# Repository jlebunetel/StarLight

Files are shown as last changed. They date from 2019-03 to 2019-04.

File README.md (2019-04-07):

# StarLight
_StarLight_ est un jeu de ping-pong à une dimension où chaque joueur se renvoie la balle à tour de rôle. Un ruban de led multicolores permet de matérialiser les raquettes et la balle qui se déplace d’un côté à l’autre, tandis que les scores s’affichent sur un écran à matrice de led multicolore.

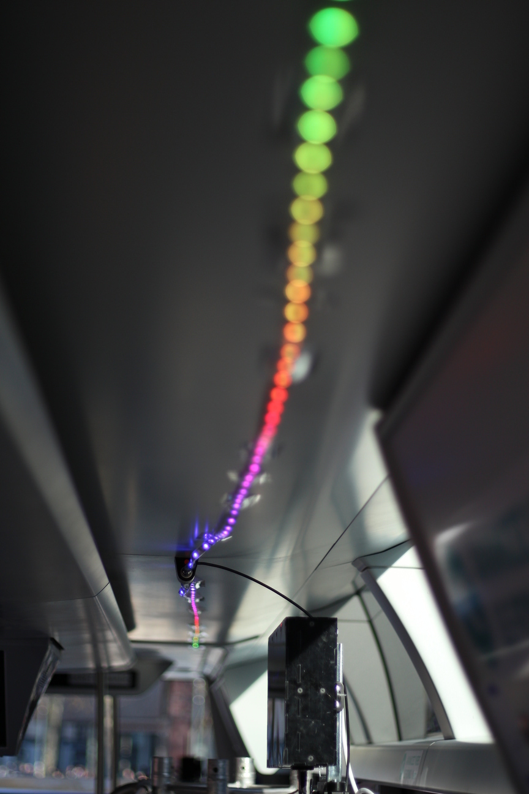
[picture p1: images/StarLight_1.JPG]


Créé lors du hackathon MétroMix 2017 à Rennes, ce jeu a été amélioré pour être intégré dans un bus lors de l’événement inOut 2019 à Rennes.

## Matériel nécessaire

__Attention : cette documentation est en cours de rédaction ...__

 * des plaques de PMMA noir opaques et translucides 3mm
 * une plaque de contreplaqué peuplier 3mm
 * du PLA pour les pièces imprimées en 3D
 * un Arduino Mega
 * une bande de LEDs RGB adressables de type *NeoPixel*
 * deux matrices de led 32 x 32
 * un Teensy 3.5
 * deux boutons d'arcade
 * une alimentation 220 V / 24 V (100W)
 * un condensateur électrolytique 1000 μF / 10 V
 * deux résistances 470 Ω
 * deux résistances 10 kΩ
 * deux condensateurs céramique 102 (1 nF)
 * un peu de câble ...

## Montage

L'ensemble des plans et des modèles 3D sont disponibles dans le dossier [models](models).

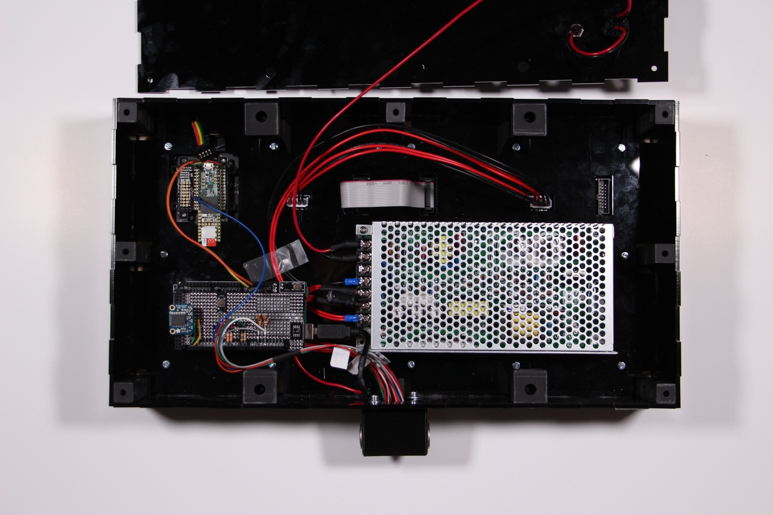
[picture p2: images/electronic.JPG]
Electronique


Les bandes de led sont alimentées en 5V et nécessitent la présence d'un condensateur de 1000 μF en parallèlele de l'alimentation.
On ajoute la résistance 470 Ω en série au signal.

LEDs

## Liens utiles

 * [Documentation du projet MétroMix 2017](http://www.wiki-rennes.fr/M%C3%A9troMix_2017/StarLight) ;

## Photos dans le bus lors d'inOut 2019
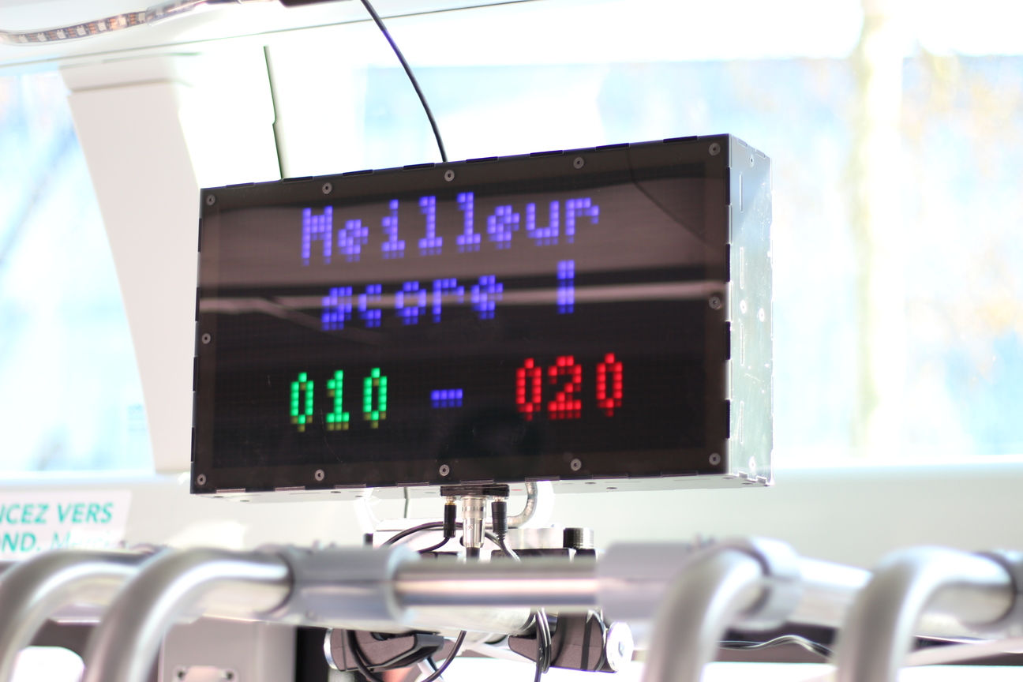
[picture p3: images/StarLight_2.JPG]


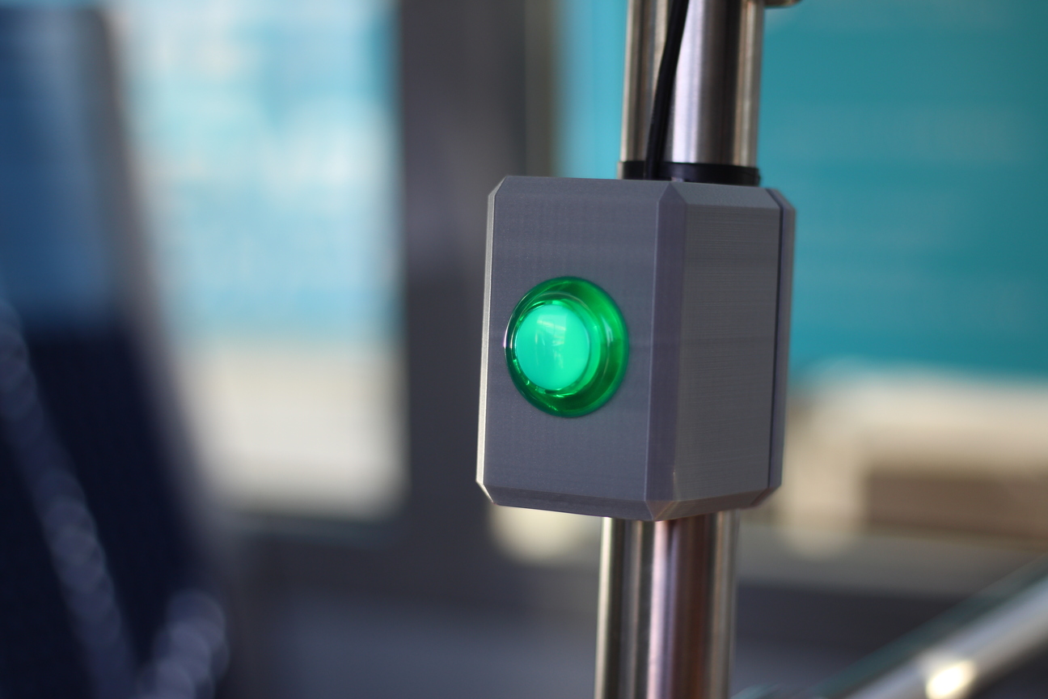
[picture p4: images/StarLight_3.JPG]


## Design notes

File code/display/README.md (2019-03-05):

# firmware for Teensy 3.5

## available commands

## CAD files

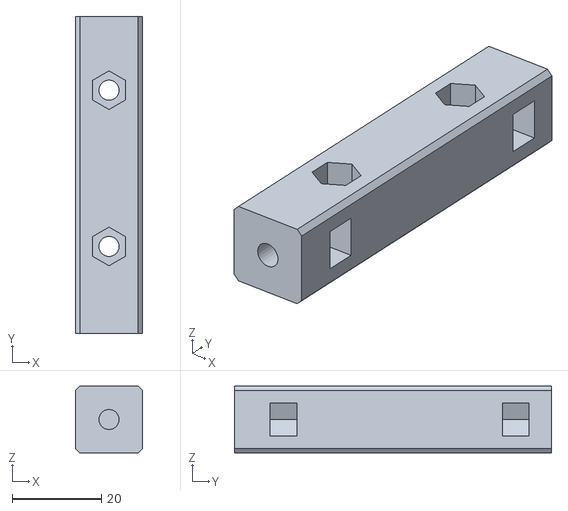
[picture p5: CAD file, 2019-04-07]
models/entretoises/milieu.stl
15.0 x 71.0 x 15.0

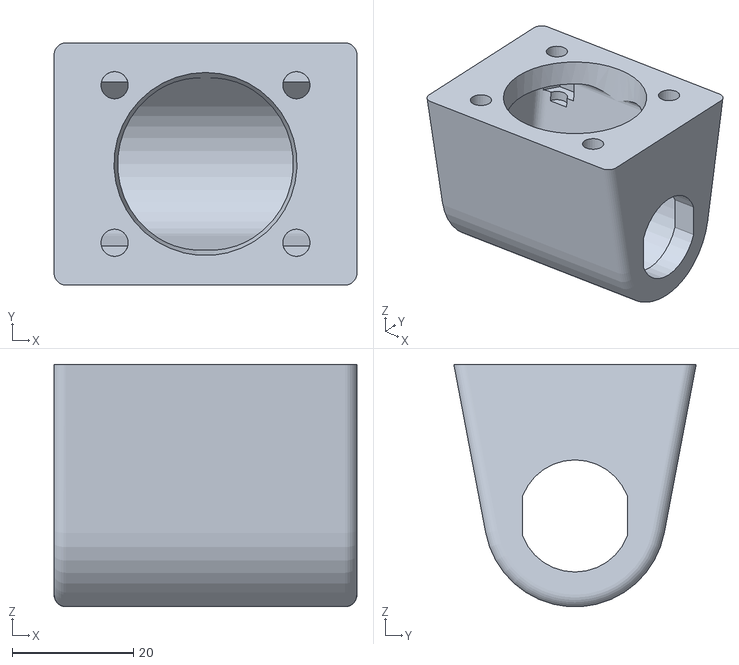
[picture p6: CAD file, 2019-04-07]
models/support_ruban.stl
50.0 x 40.0 x 40.0

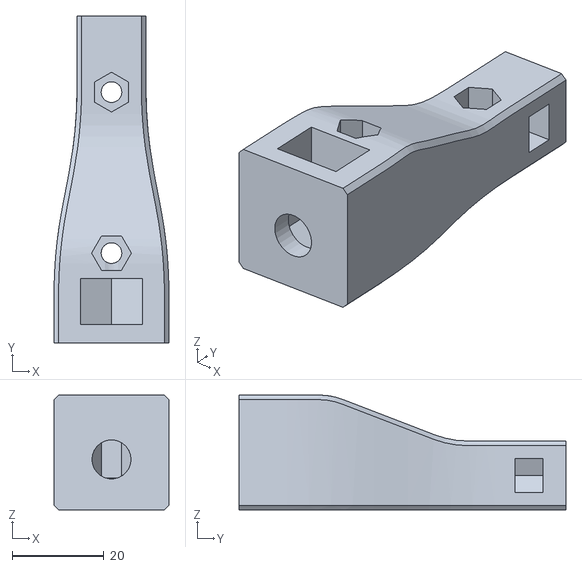
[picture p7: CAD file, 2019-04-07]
models/entretoises/support_M8.stl
25.0 x 71.0 x 25.0

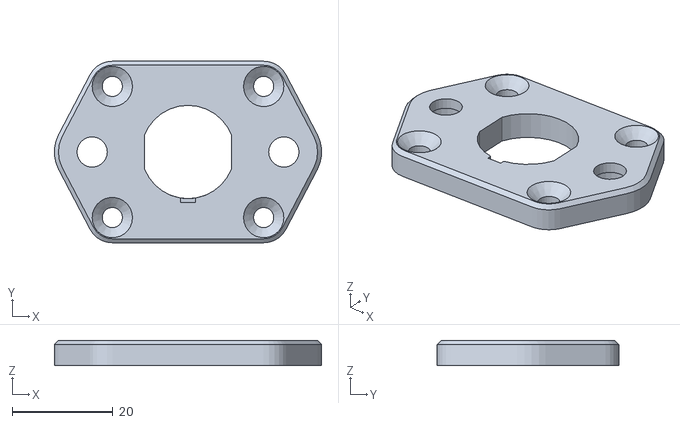
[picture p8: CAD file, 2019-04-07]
models/passage_connecteurs.stl
52.9 x 36.0 x 5.00

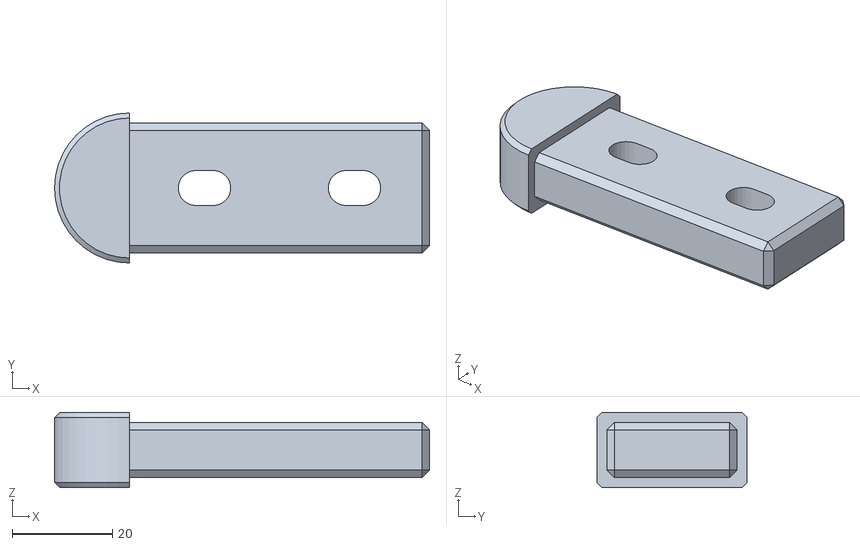
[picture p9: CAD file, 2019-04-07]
models/embout_support.stl
75.0 x 30.0 x 15.0

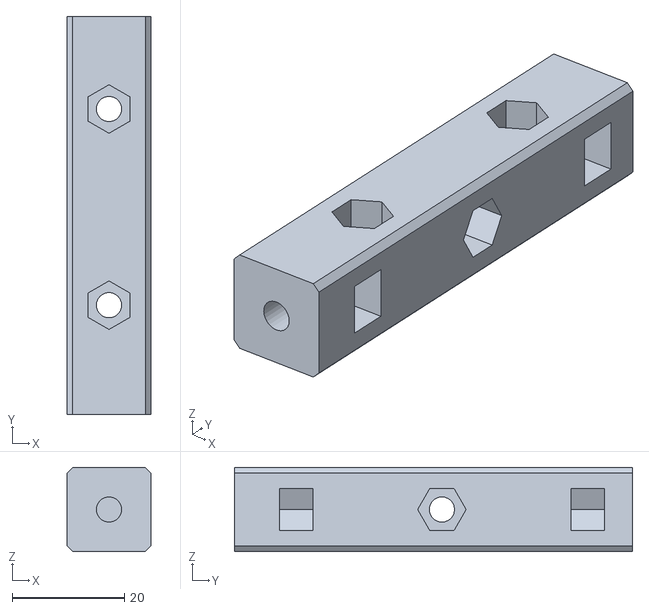
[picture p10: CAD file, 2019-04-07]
models/entretoises/angle.stl
15.0 x 71.0 x 15.0

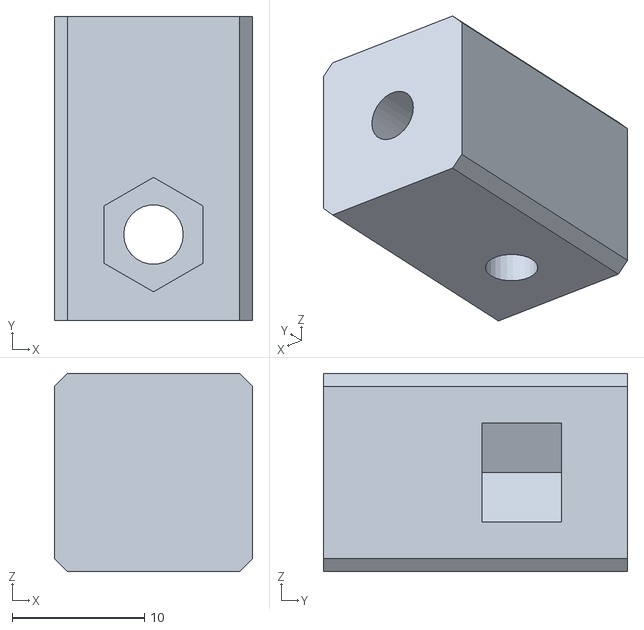
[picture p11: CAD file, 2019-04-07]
models/entretoises/milieu_court.stl
15.0 x 23.0 x 15.0

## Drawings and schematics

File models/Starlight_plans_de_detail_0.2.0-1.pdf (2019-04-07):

A

B

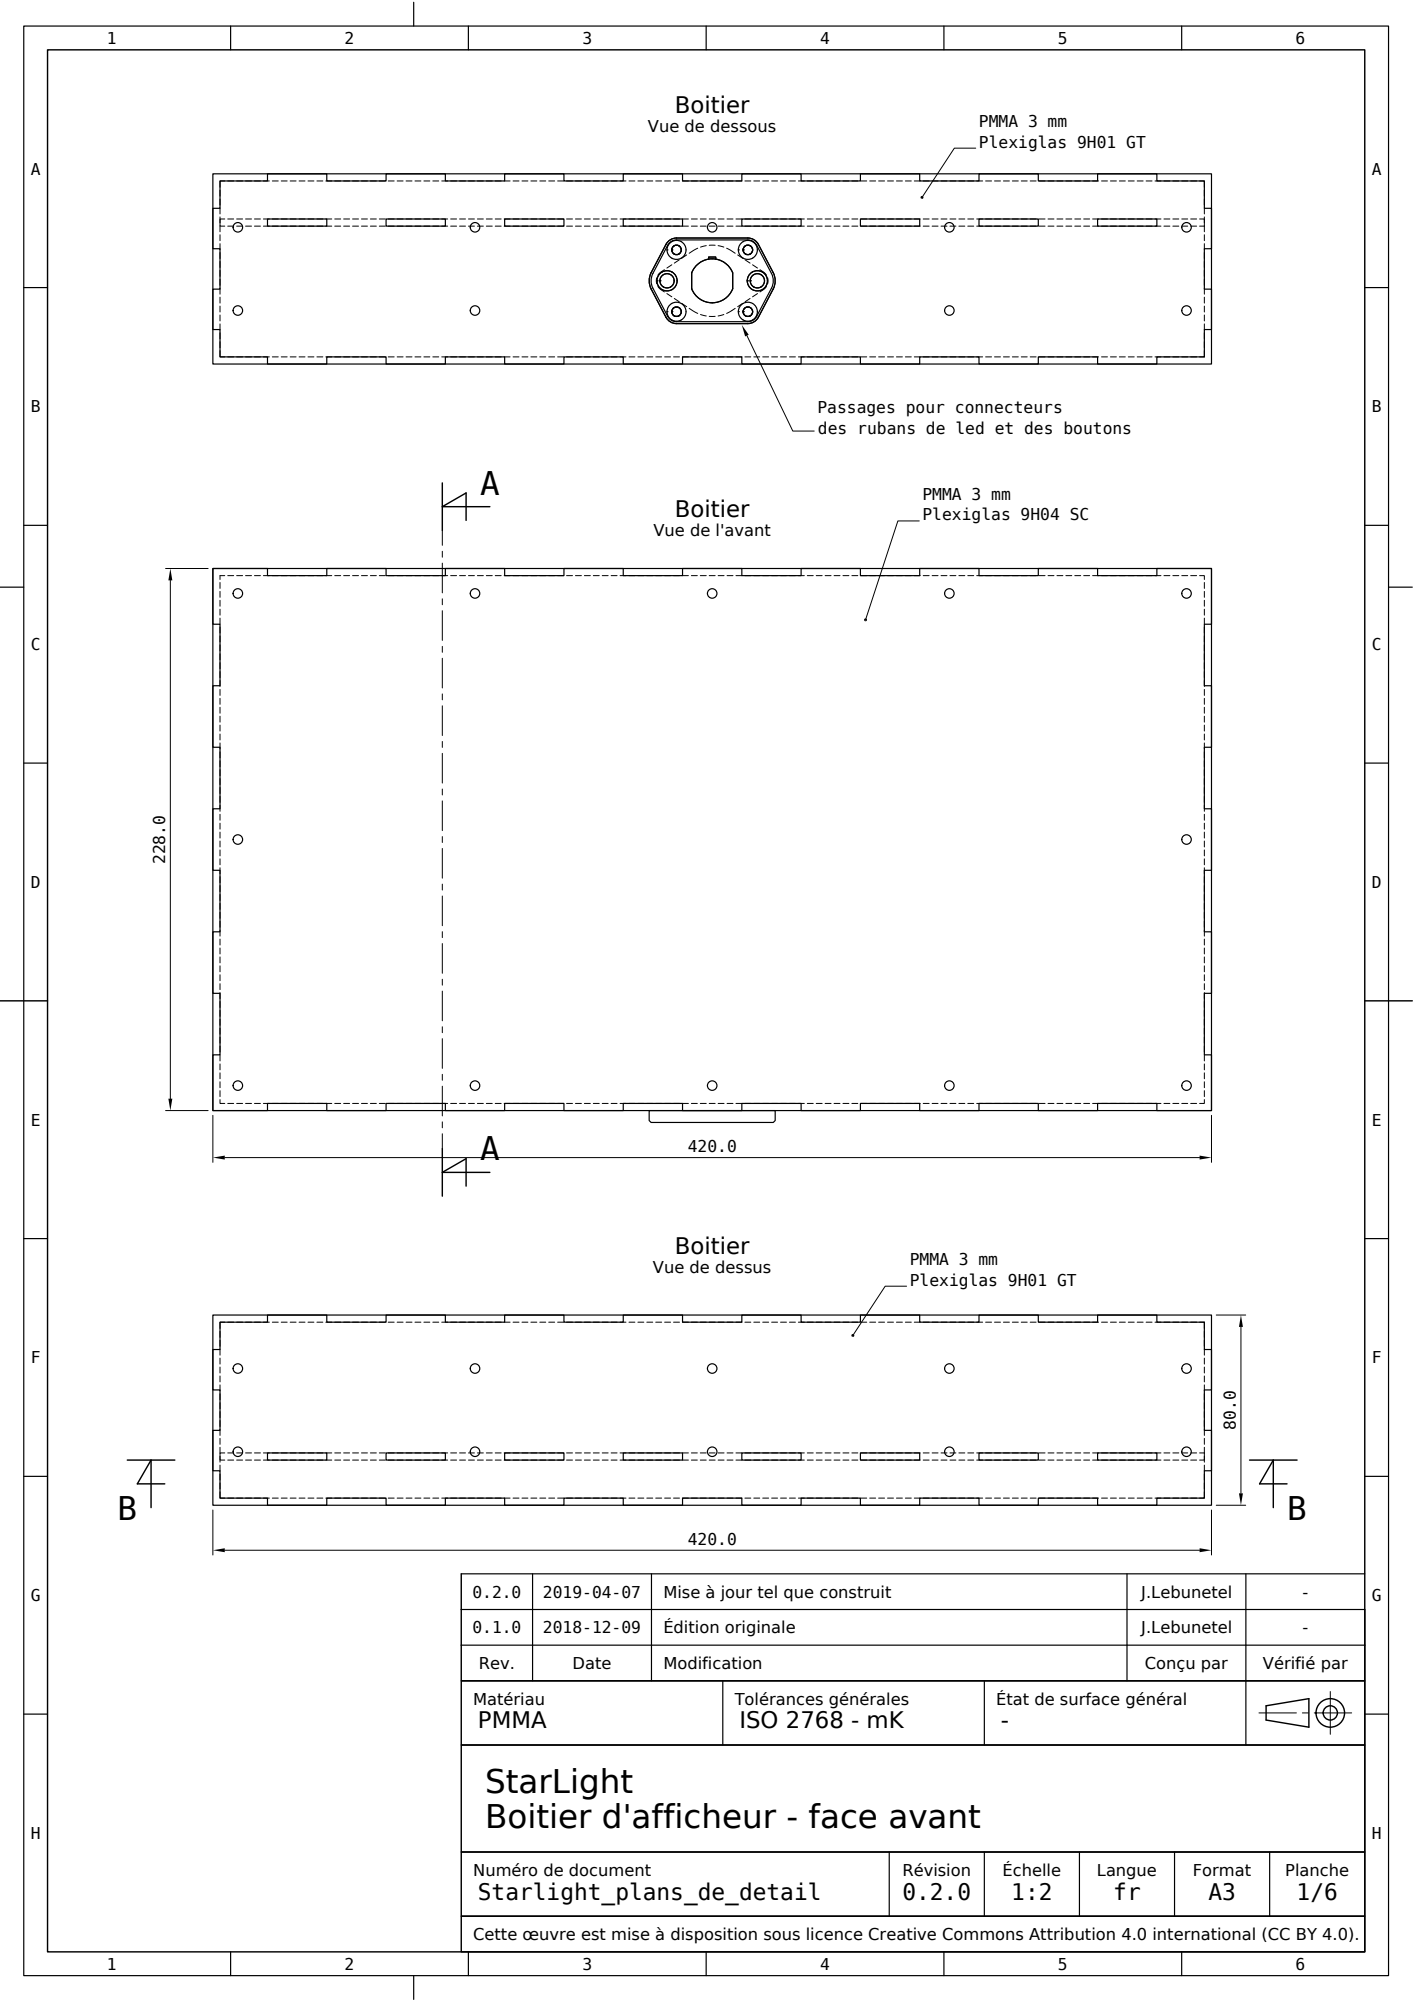
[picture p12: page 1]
Boitier; PMMA 3 mm; Plexiglas; Boitier d'afficheur -; face avant; StarLight; PMMA; ISO 2768 -; Rev.; Date; Modification; Édition originale; Lebunetel; Conçu par; Vérifié par; Matériau; Tolérances générales; État de surface général; Planche 1/6; Format A3; Langue fr; Échelle 1:2; Révision; Starlight_; plans_; detail; Cette uvre est mise à disposition sous licence Creative Commons Attribution 4.; 0 international (CC BY 4.; Passages; pour; connecteurs; des; rubans; led et des; boutons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

Vue de dessous

Vue de l'avant

Vue de dessus

Numéro de document

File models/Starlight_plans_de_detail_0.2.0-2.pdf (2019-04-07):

A

B

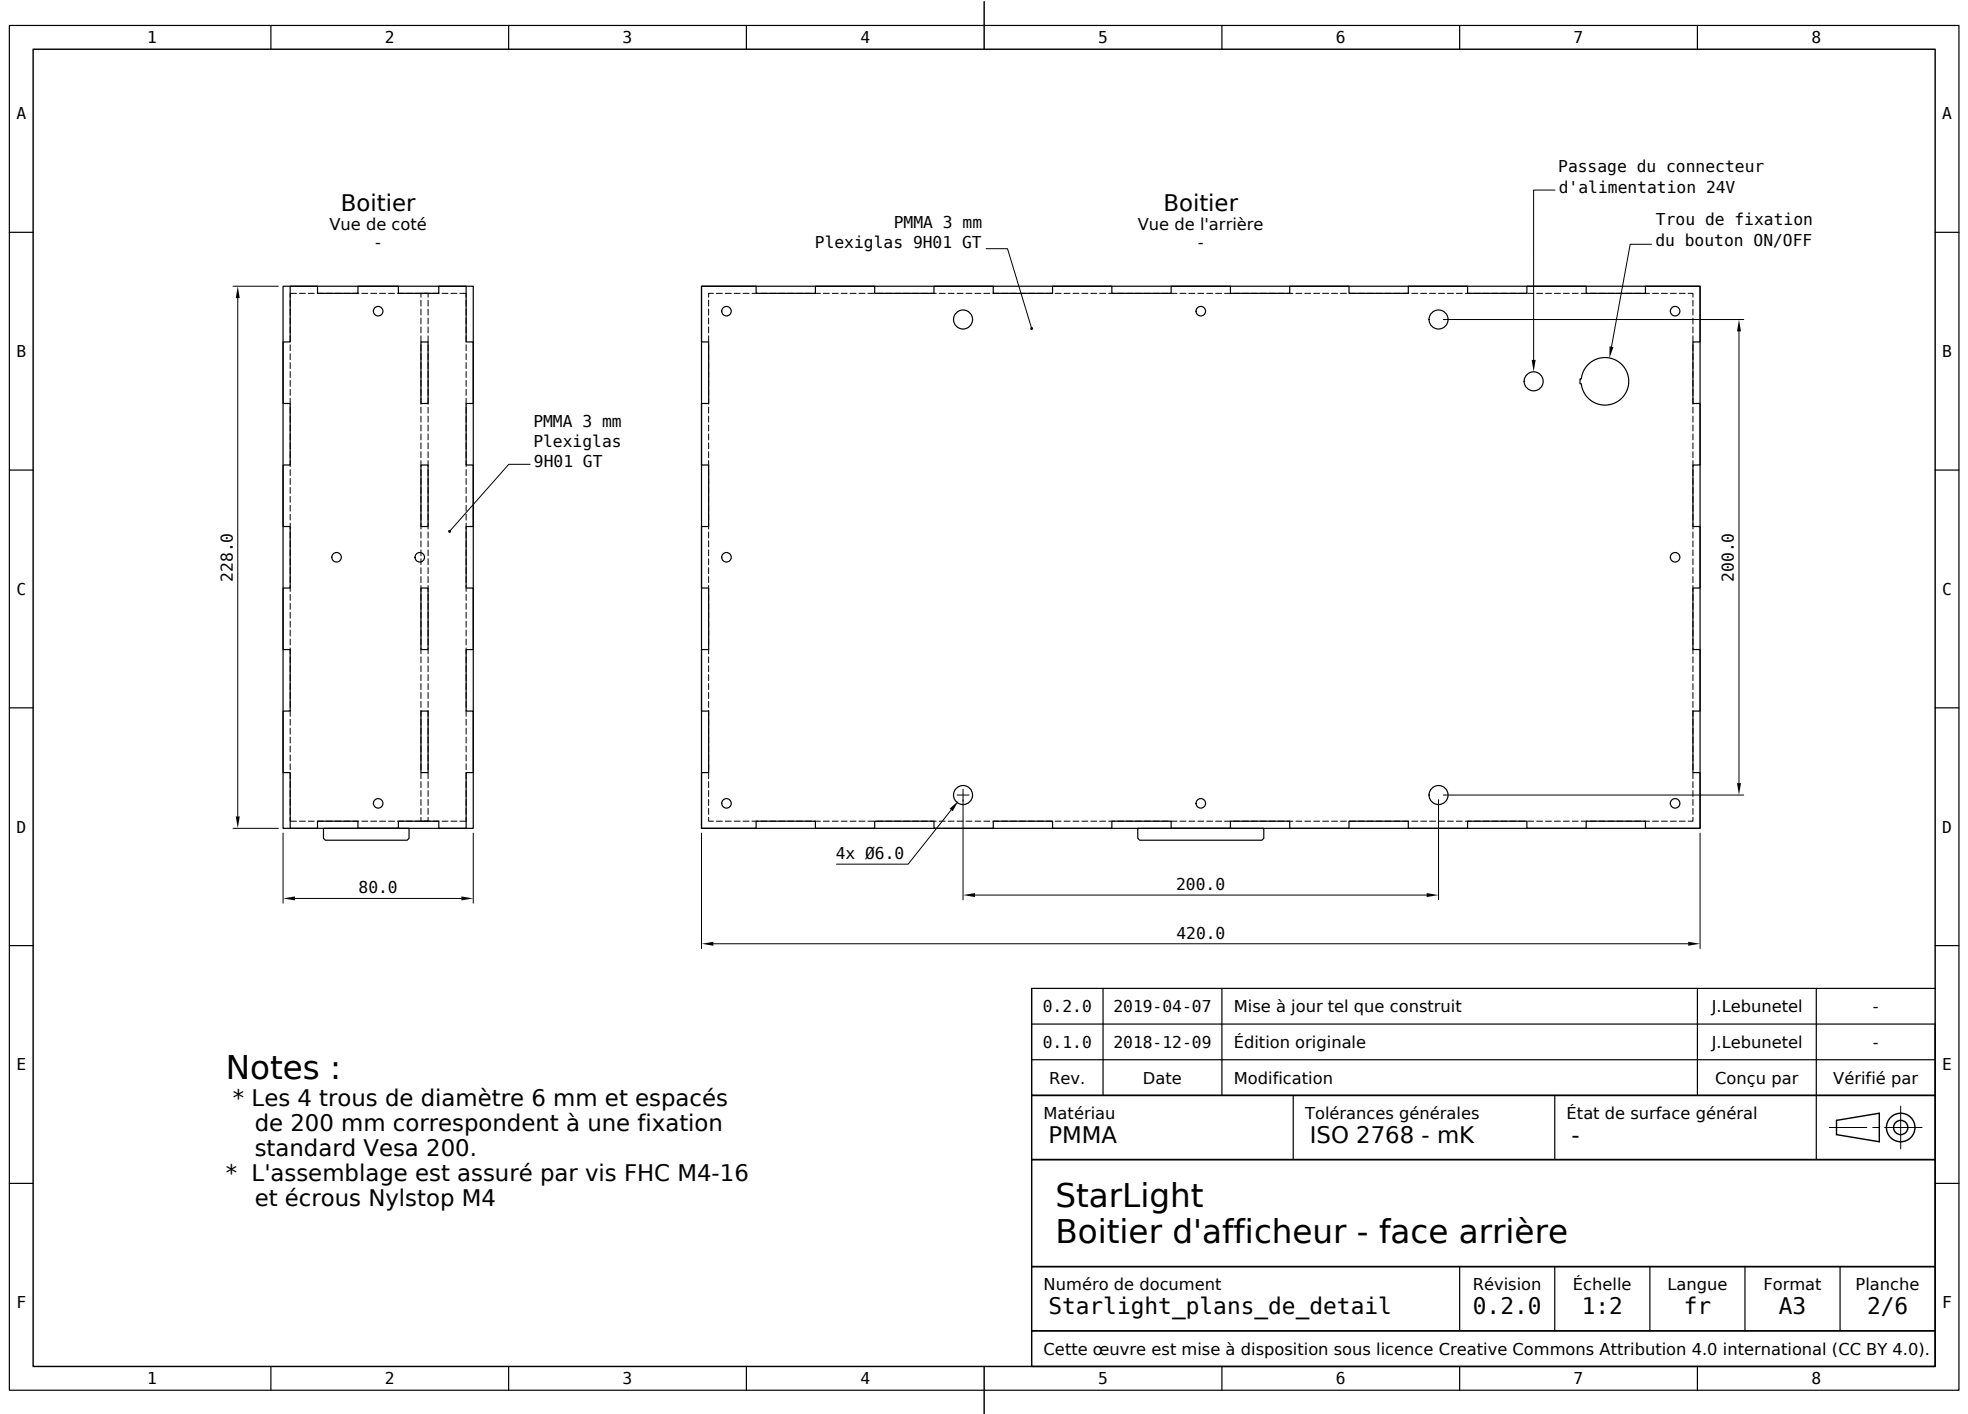
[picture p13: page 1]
Boitier; PMMA 3 mm; Plexiglas; Passage; connecteur; d'alimentation; Trou; fixation; bouton; ON/OFF; Boitier d'afficheur -; face arrière; StarLight; PMMA; ISO 2768 -; Rev.; Date; Modification; Édition originale; Lebunetel; Conçu par; Vérifié par; Matériau; Tolérances générales; État de surface général; Planche 2/6; Format A3; Langue fr; Échelle 1:2; Révision; Starlight_; plans_; detail; Cette uvre est mise à disposition sous licence Creative Commons Attribution 4.; 0 international (CC BY 4.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

Vue de coté

Vue de l'arrière

* Les 4 trous de diamètre 6 mm et espacés
de 200 mm correspondent à une fixation

standard Vesa 200.
et écrous Nylstop M4

Numéro de document

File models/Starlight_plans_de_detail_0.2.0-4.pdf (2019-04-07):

A

B

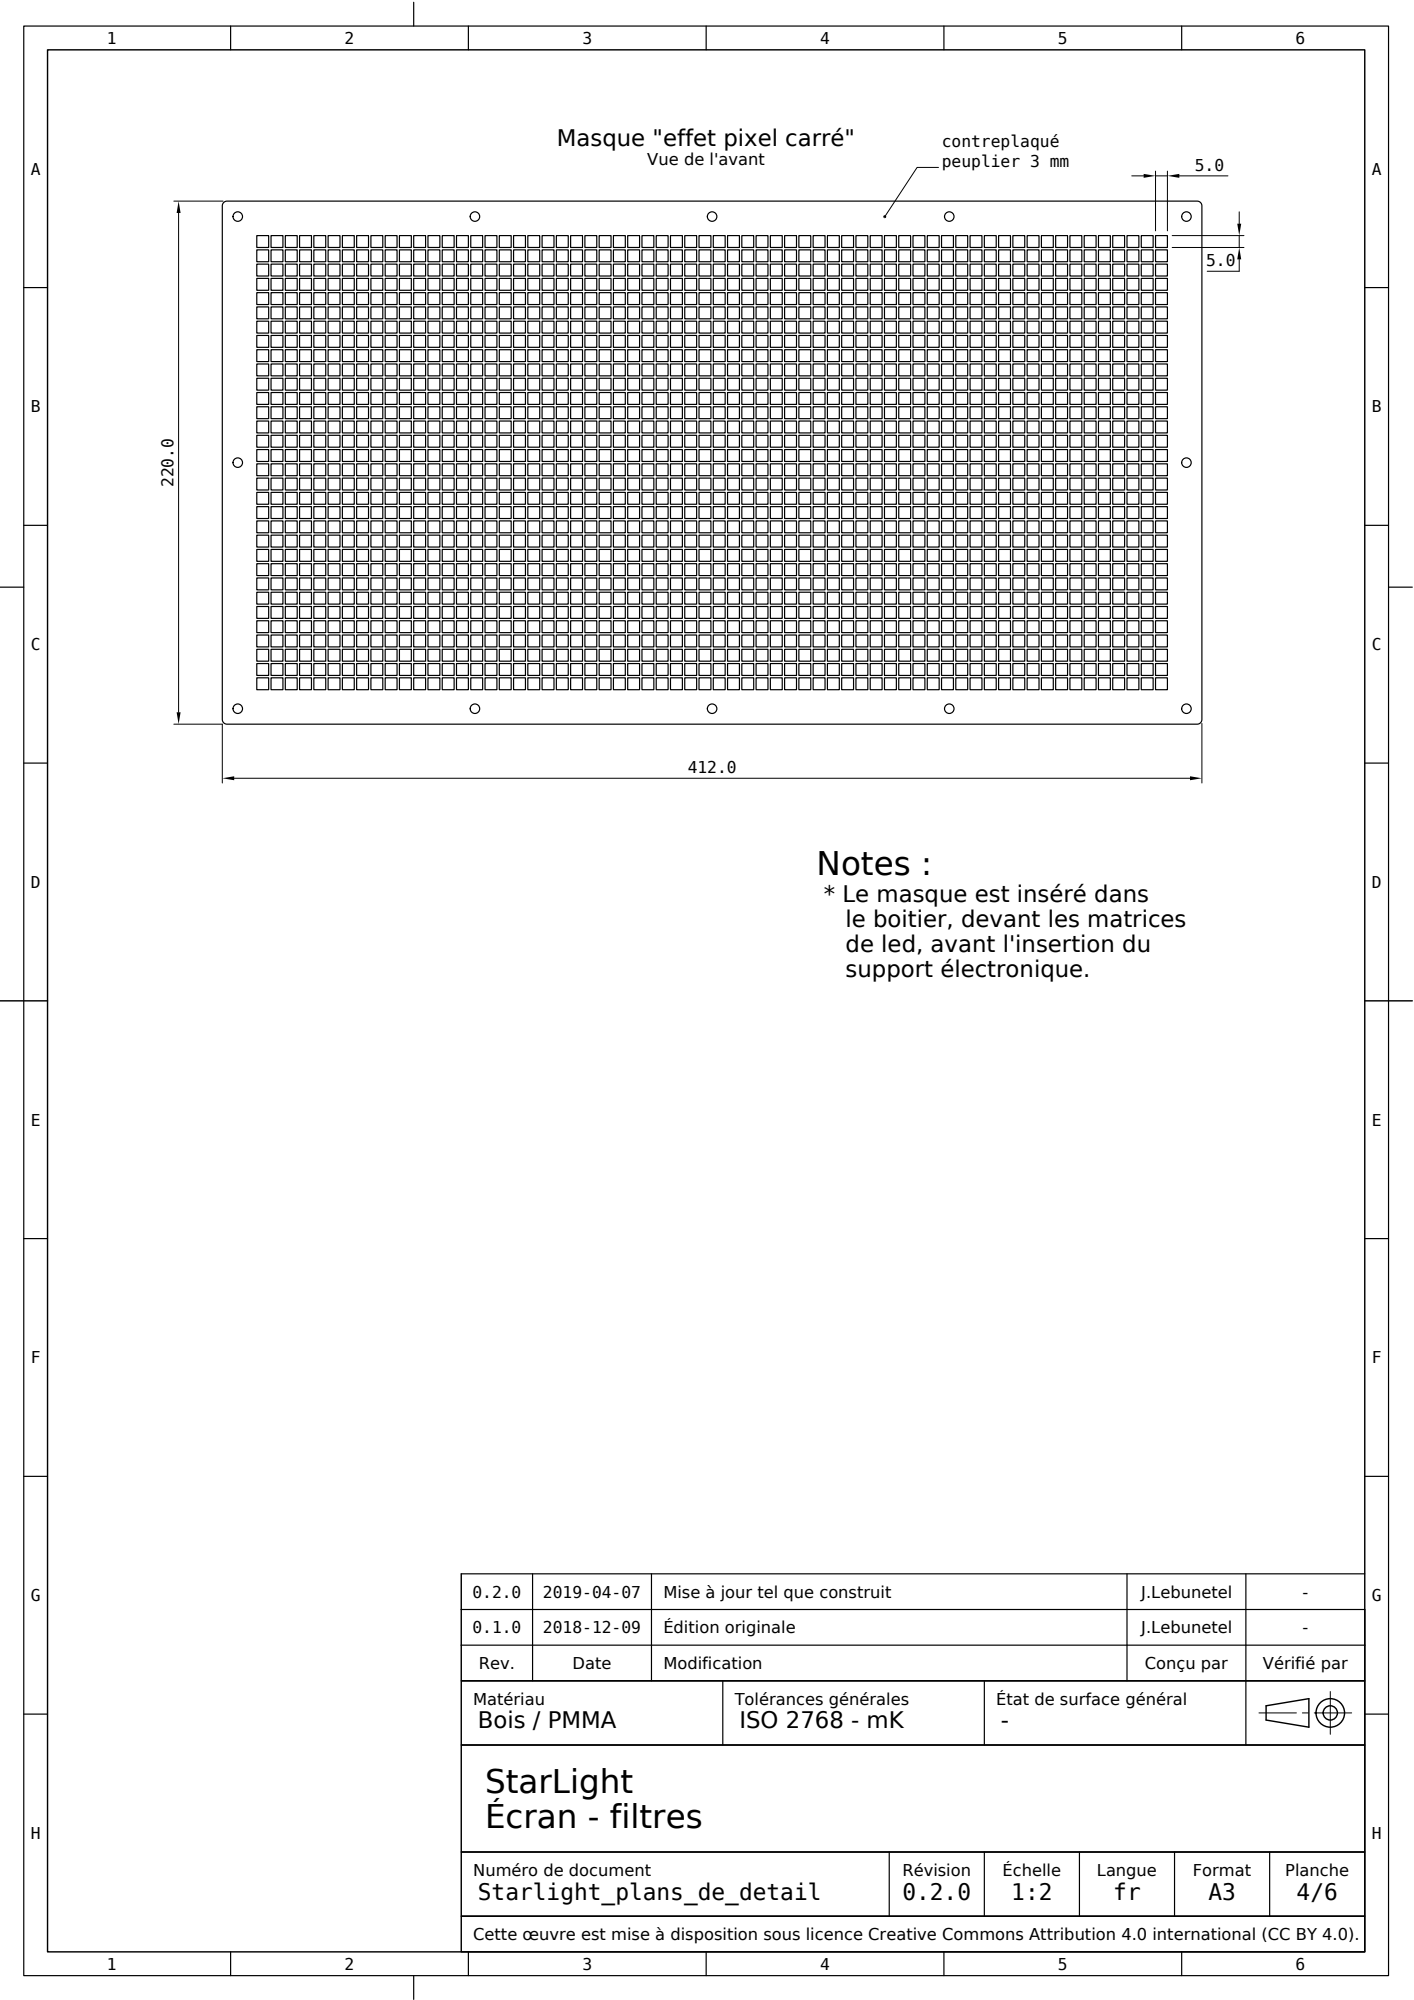
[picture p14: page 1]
Écran -; filtres; StarLight; Bois / PMMA; ISO 2768 -; Rev.; Date; Modification; Édition originale; Lebunetel; Conçu par; Vérifié par; Matériau; Tolérances générales; État de surface général; Planche 4/6; Format A3; Langue fr; Échelle 1:2; Révision; Starlight_; plans_; detail; Cette uvre est mise à disposition sous licence Creative Commons Attribution 4.; 0 international (CC BY 4.; contreplaqué; peuplier; Notes :; le boitier,; devant les matrices; de led,; avant l'insertion du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

Masque "effet pixel carré"

Vue de l'avant

* Le masque est inséré dans

Numéro de document

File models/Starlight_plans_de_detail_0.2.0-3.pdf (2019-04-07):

## Section A-A

A

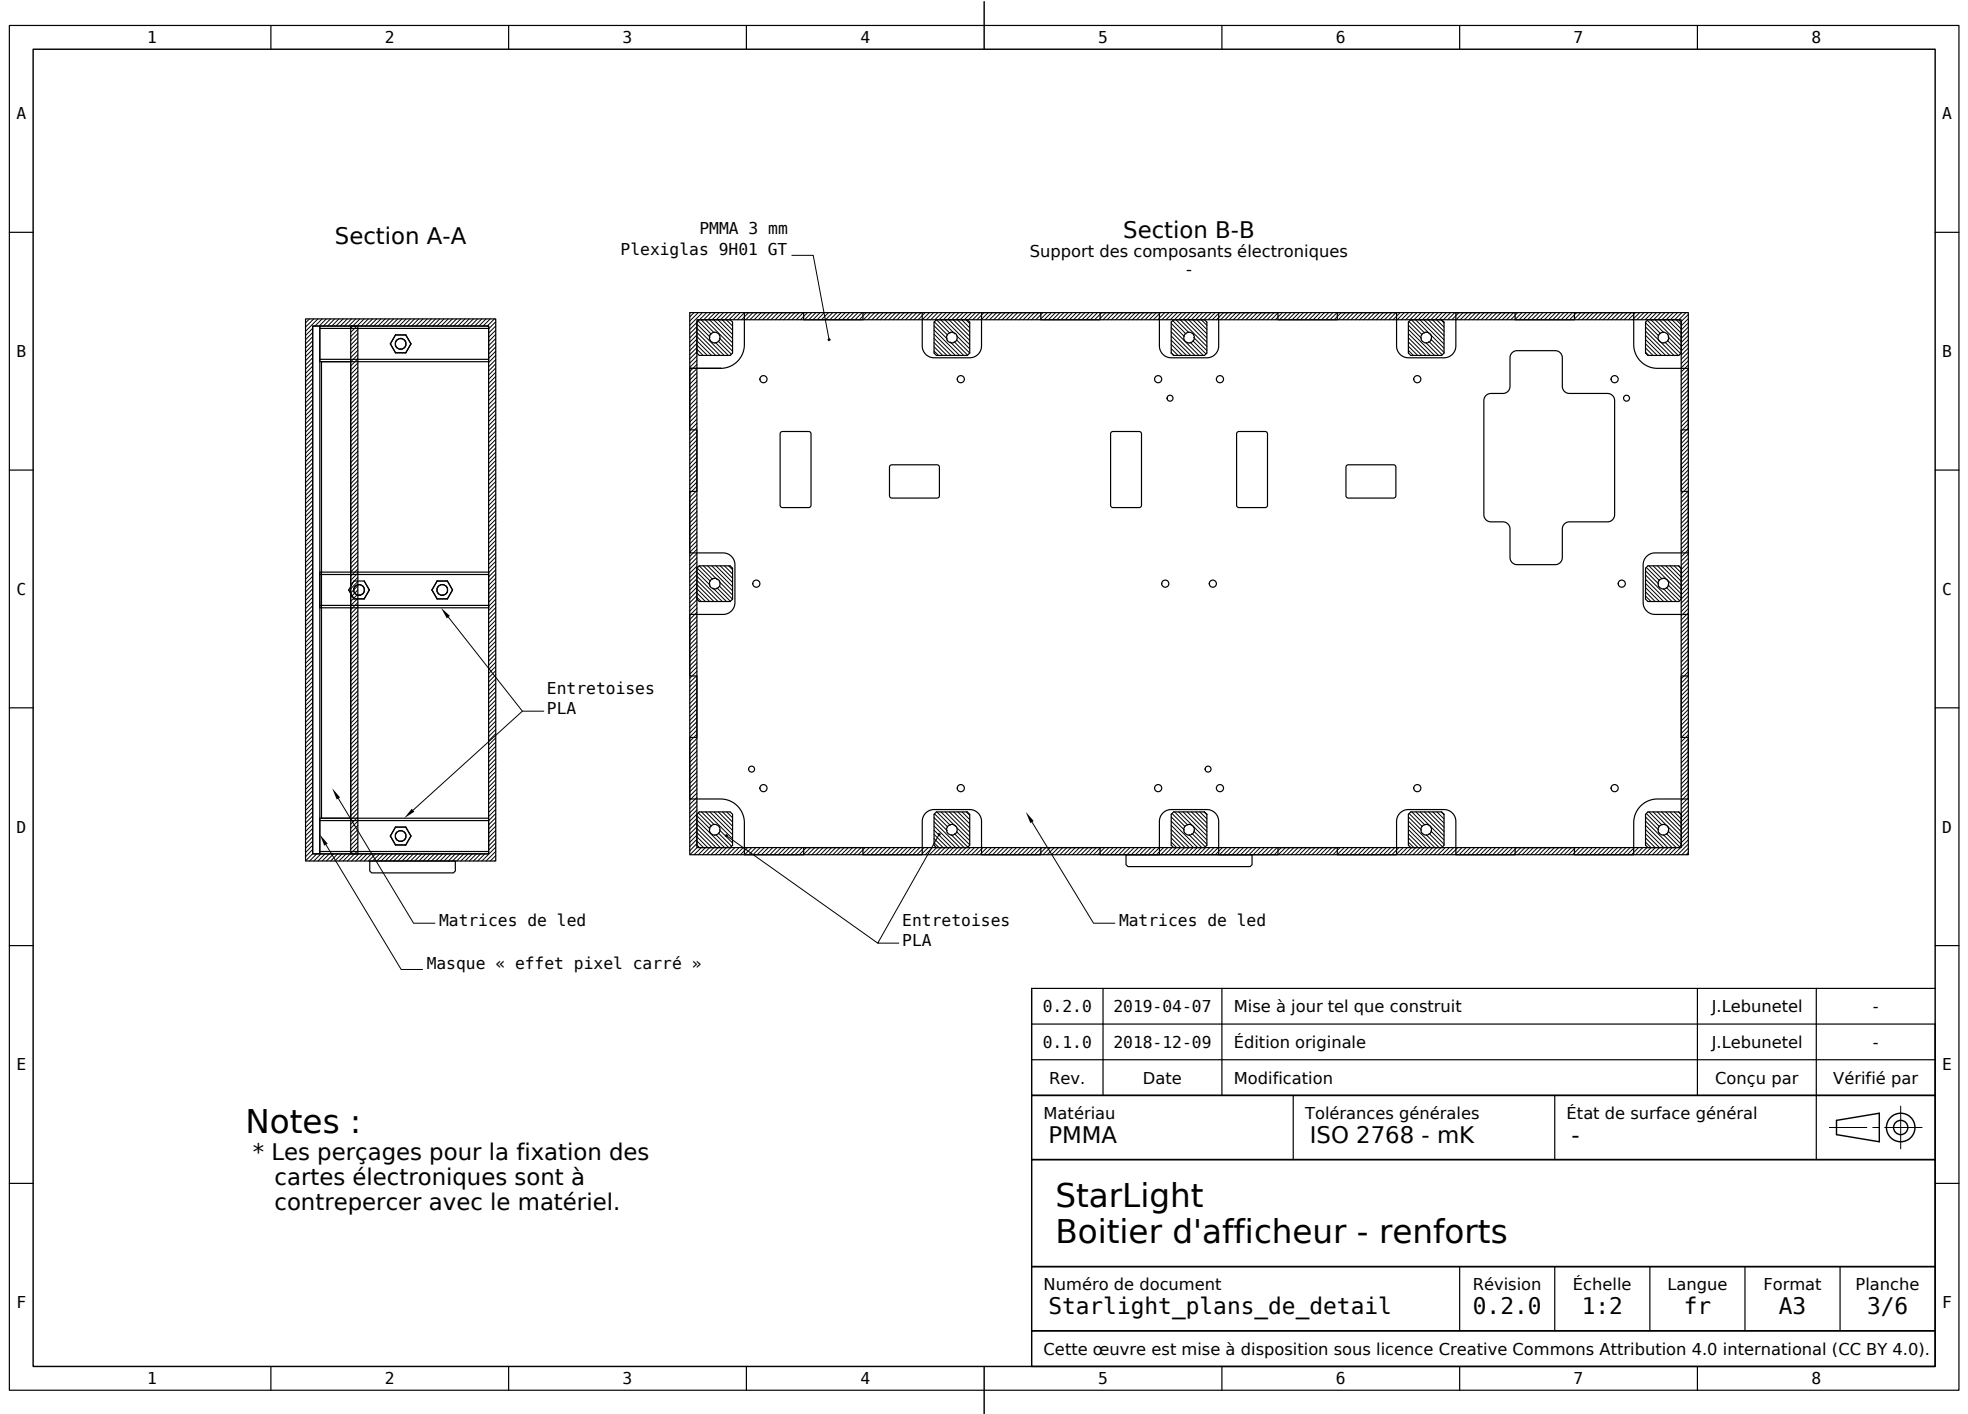
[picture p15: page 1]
Section B-; Boitier d'afficheur -; renforts; StarLight; PMMA; ISO 2768 -; Rev.; Date; Modification; Édition originale; Lebunetel; Conçu par; Vérifié par; Matériau; Tolérances générales; État de surface général; Planche 3/6; Format A3; Langue fr; Échelle 1:2; Révision; Starlight_; plans_; detail; Cette uvre est mise à disposition sous licence Creative Commons Attribution 4.; 0 international (CC BY 4.; Mise à jour tel que construit; PMMA 3 mm; Plexiglas; Masque; effet pixel carré »; Matrices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

Support des composants électroniques

* Les perçages pour la fixation des
cartes électroniques sont à
contrepercer avec le matériel.

Numéro de document

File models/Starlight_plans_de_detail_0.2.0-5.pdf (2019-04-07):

A

B

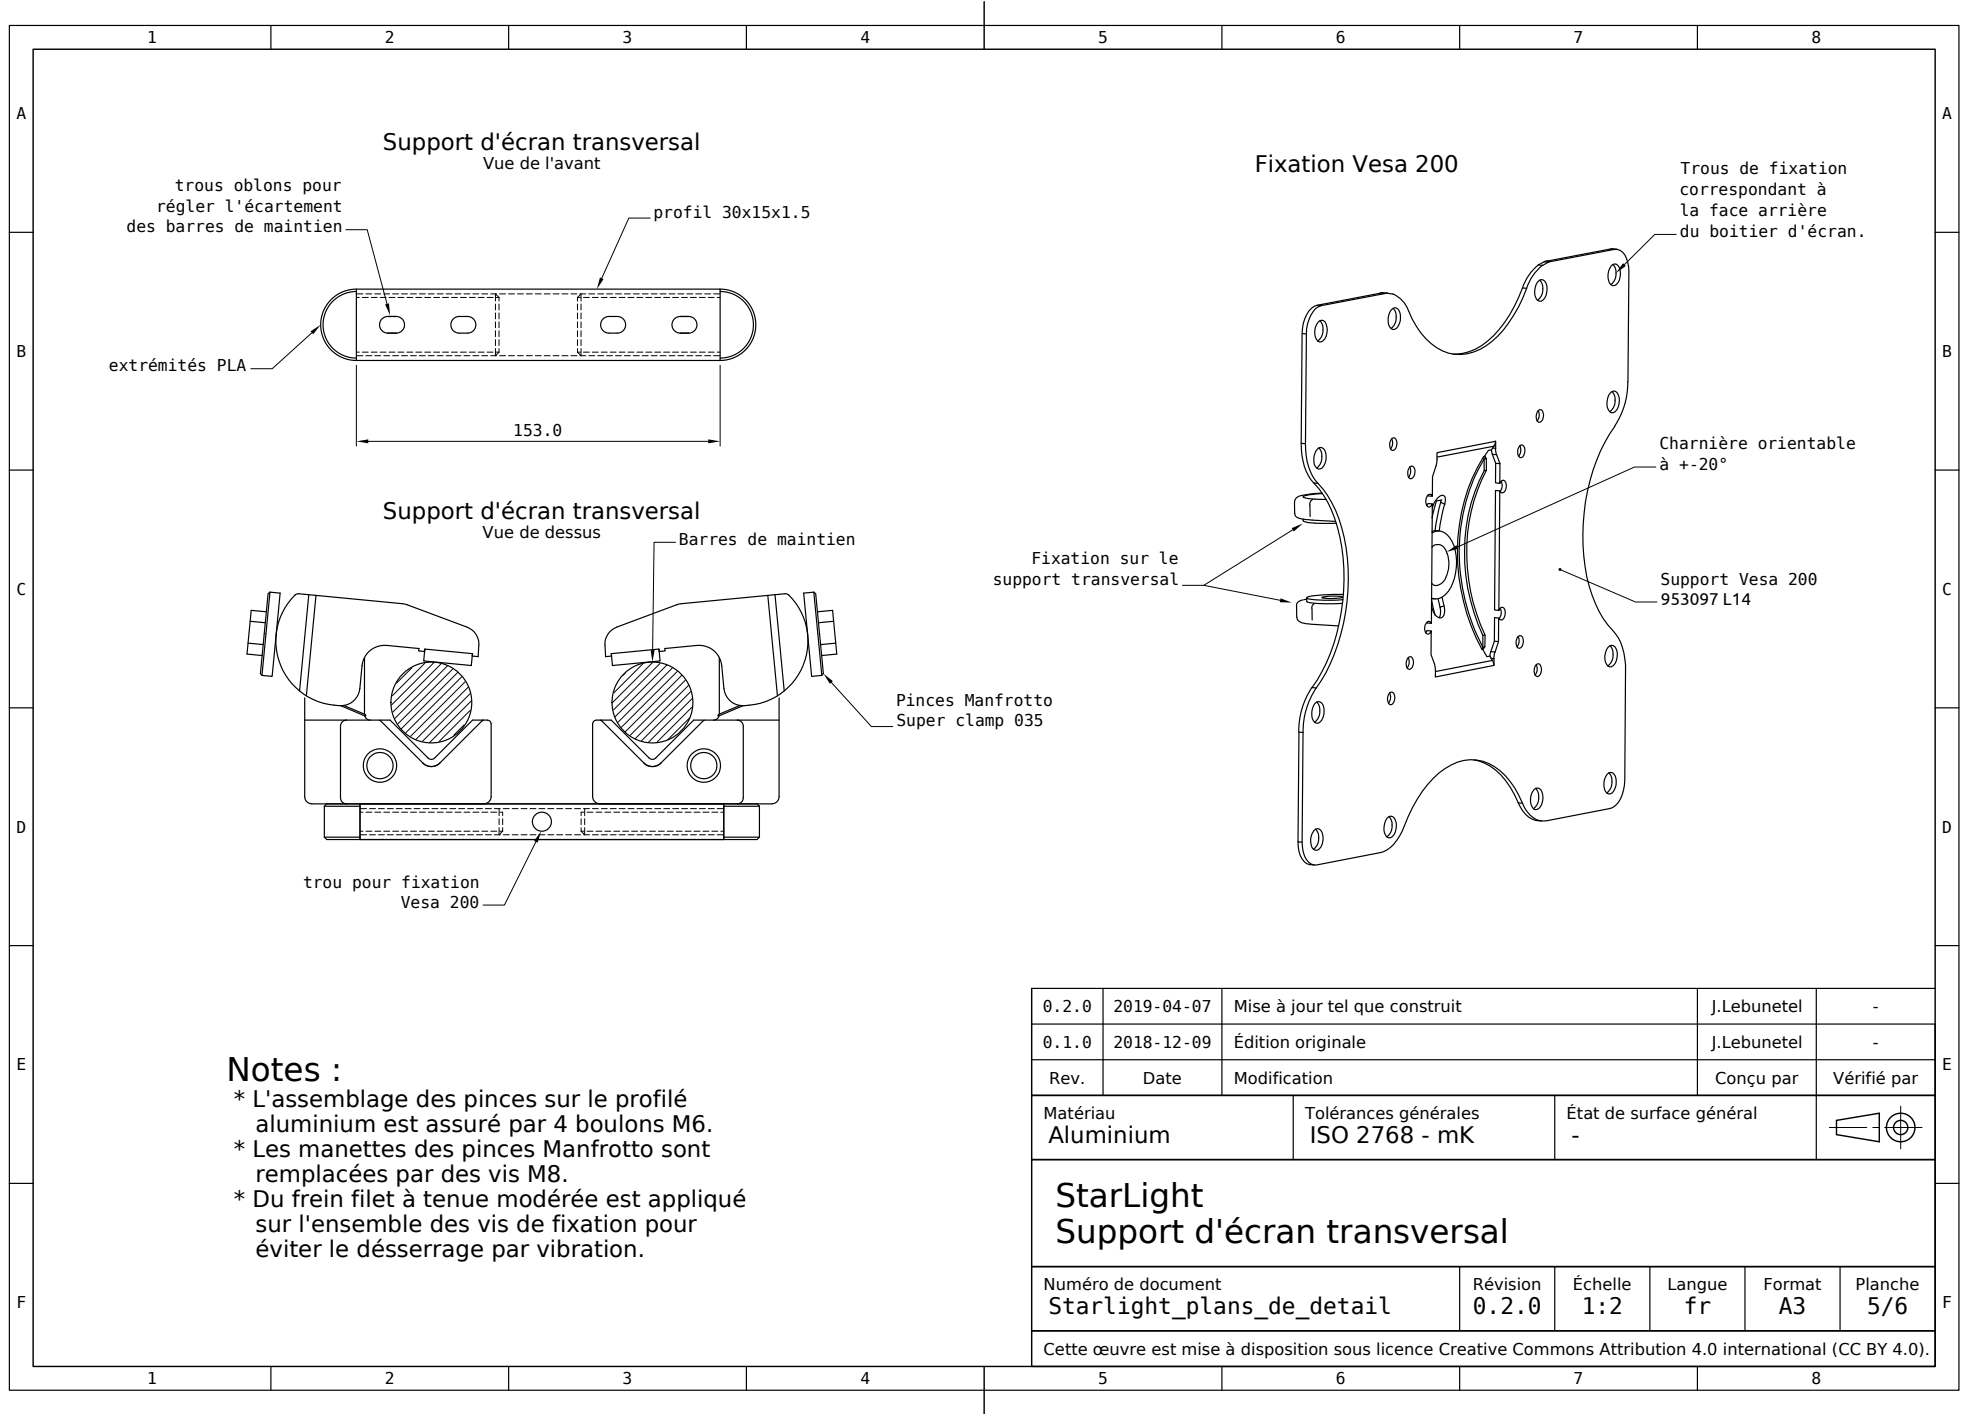
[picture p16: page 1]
Aluminium; ISO 2768 -; Rev.; Date; Modification; Édition originale; Lebunetel; Conçu par; Vérifié par; Matériau; Tolérances générales; État de surface général; Planche 5/6; Format A3; Langue fr; Échelle 1:2; Révision; Starlight_; plans_; detail; Cette uvre est mise à disposition sous licence Creative Commons Attribution 4.; 0 international (CC BY 4.; Notes :; trous; oblons; pour; régler; l'écartement; des; barres; maintien; extrémités; PLA; Mise à jour tel que construit; trou; fixation; Vesa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

Support d'écran transversal

Vue de l'avant

Vue de dessus

* L'assemblage des pinces sur le profilé
aluminium est assuré par 4 boulons M6.

* Les manettes des pinces Manfrotto sont
remplacées par des vis M8.
* Du frein filet à tenue modérée est appliqué

StarLight

sur l'ensemble des vis de fixation pour
éviter le désserrage par vibration.

Numéro de document

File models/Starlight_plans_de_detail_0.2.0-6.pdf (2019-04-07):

A

B

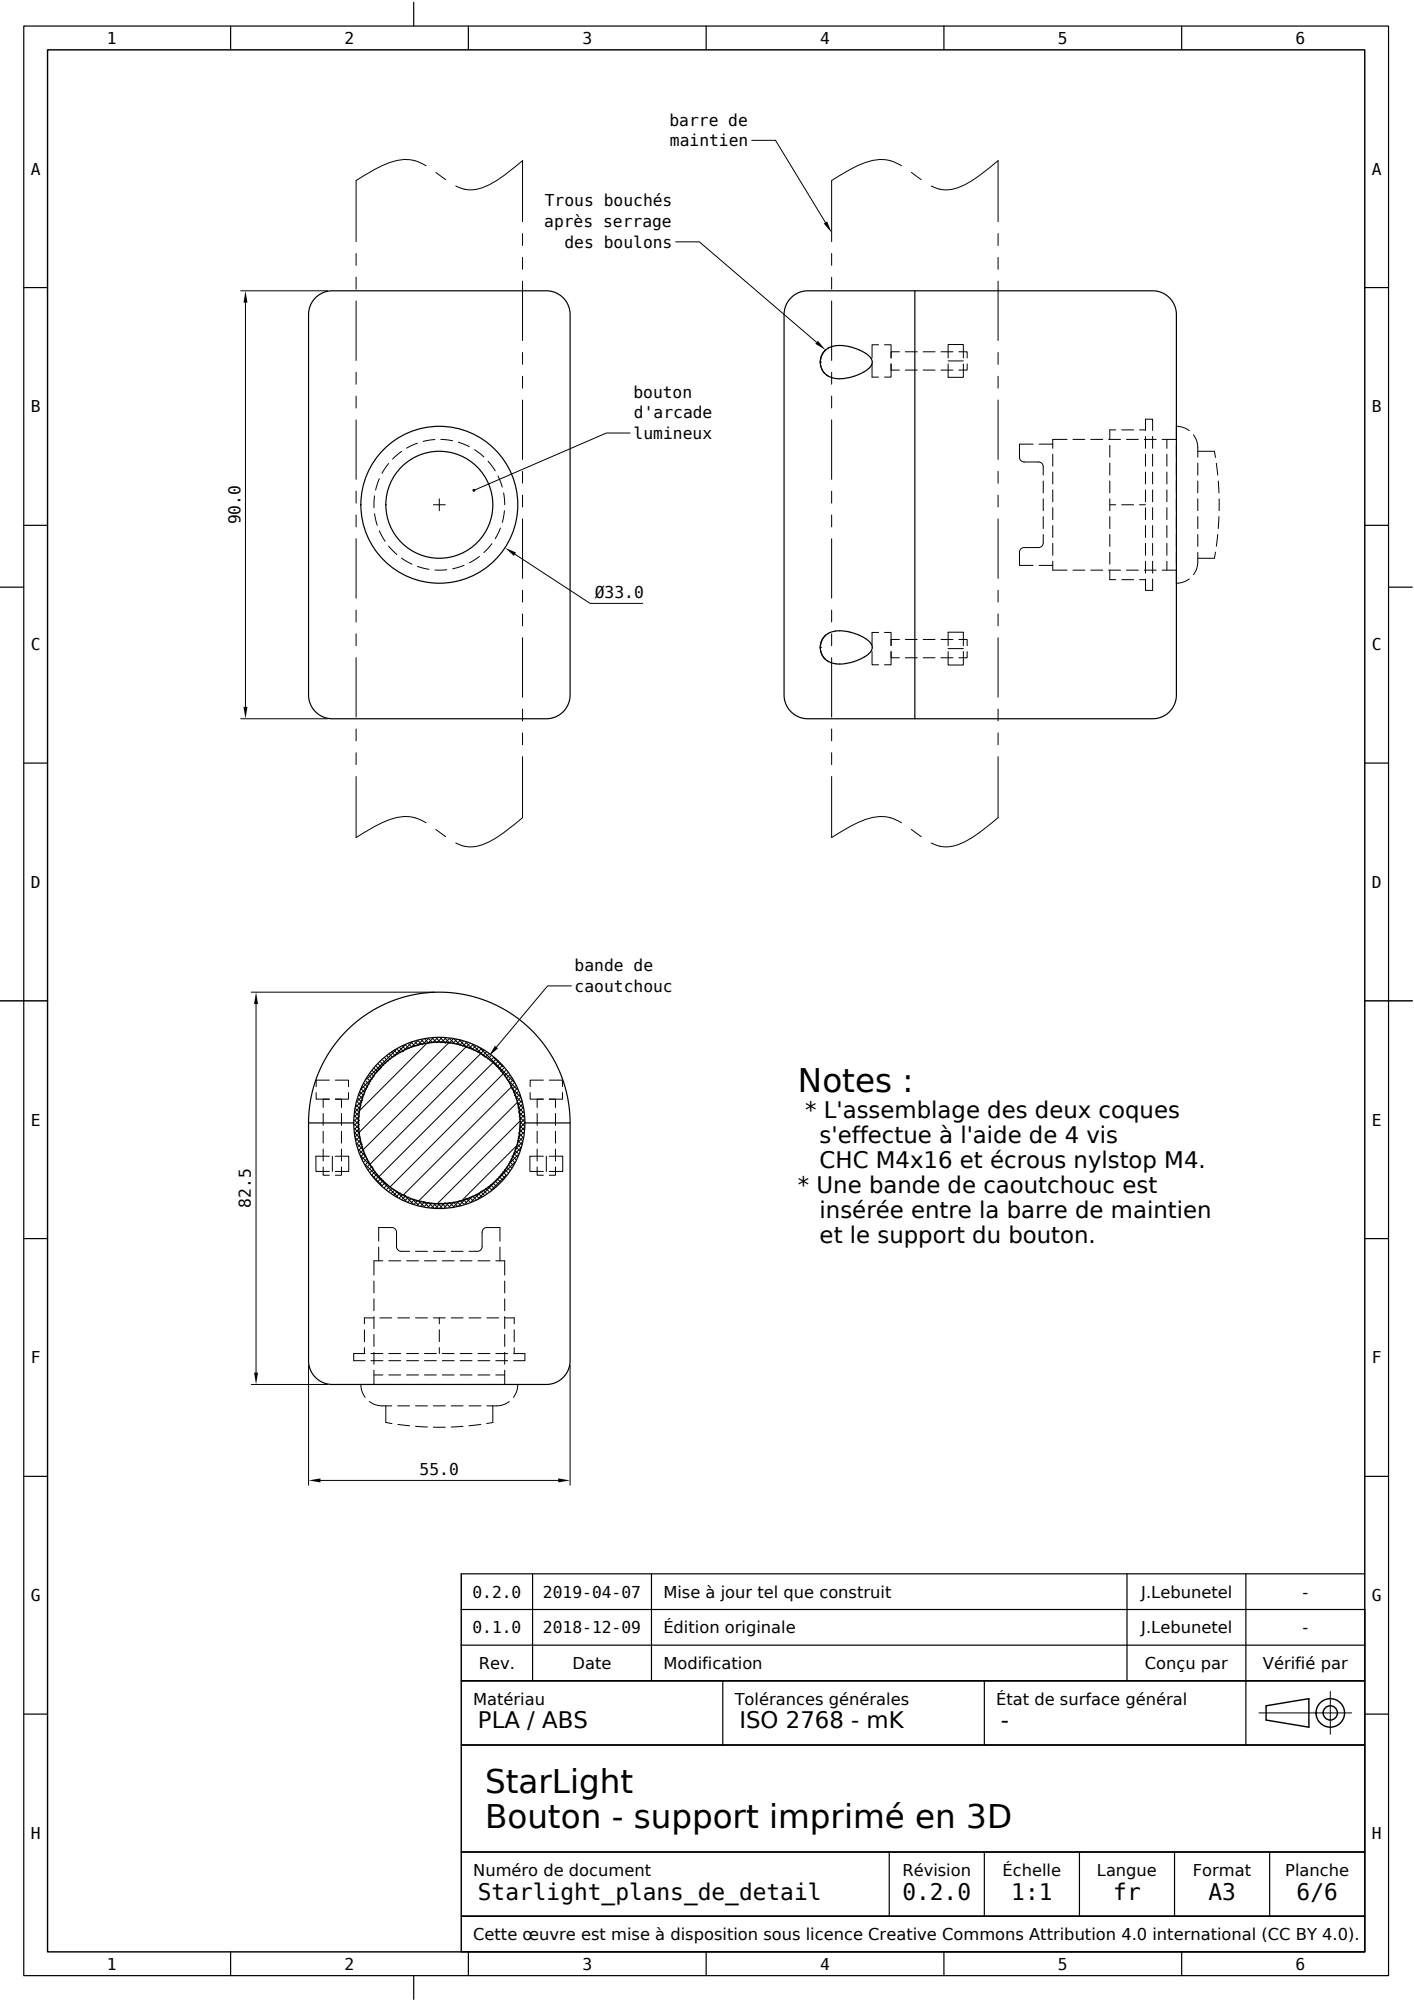
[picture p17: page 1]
bande; caoutchouc; Notes :; barre; maintien; bouton; d'arcade; lumineux; Bouton -; support imprimé en 3D; StarLight; PLA / ABS; ISO 2768 -; Rev.; Date; Modification; Édition originale; Lebunetel; Conçu par; Vérifié par; Matériau; Tolérances générales; État de surface général; Planche 6/6; Format A3; Langue fr; Échelle 1:1; Révision; Starlight_; plans_; detail; Cette uvre est mise à disposition sous licence Creative Commons Attribution 4.; 0 international (CC BY 4.; Trous; bouchés; après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

* L'assemblage des deux coques
s'effectue à l'aide de 4 vis
CHC M4x16 et écrous nylstop M4.

* Une bande de caoutchouc est
insérée entre la barre de maintien

et le support du bouton.

Numéro de document

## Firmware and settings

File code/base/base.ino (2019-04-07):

/*
   This sketch is the main program of the game.
*/

// librairies
#include "button.h"
#include "led.h"
#include <Adafruit_NeoPixel.h>
#include <Wire.h>
#include "RTClib.h"


// configuration
#define RED_BUTTON_PIN    10
#define GREEN_BUTTON_PIN  12

#define RED_LED_PIN        2
#define GREEN_LED_PIN      3

#define RED_STRIP_PIN      6
#define GREEN_STRIP_PIN    7

#define RED_STRIP_LENGTH   150
#define GREEN_STRIP_LENGTH 149

#define DEFAULT_RACKET_LENGTH 15
#define MIN_RACKET_LENGTH      5
int racketLength = DEFAULT_RACKET_LENGTH;

#define BLINK_DELAY 500

#define DEFAULT_BALL_SPEED 22
#define MAX_BALL_SPEED 1
int ballSpeed = DEFAULT_BALL_SPEED;

unsigned long stopTop;
#define STOP_DELAY 10000

// variables configuration
Button redButton;
Button greenButton;

Led redLed;
Led greenLed;

Adafruit_NeoPixel redStrip = Adafruit_NeoPixel(RED_STRIP_LENGTH, RED_STRIP_PIN, NEO_GRB + NEO_KHZ800);
Adafruit_NeoPixel greenStrip = Adafruit_NeoPixel(GREEN_STRIP_LENGTH, GREEN_STRIP_PIN, NEO_GRB + NEO_KHZ800);

// HTML colors
#define COLOR_WHITE   0xFFFFFF
#define COLOR_SILVER  0xC0C0C0
#define COLOR_GRAY    0x808080
#define COLOR_BLACK   0x000000
#define COLOR_RED     0xFF0000
#define COLOR_MAROON  0x800000
#define COLOR_YELLOW  0xFFFF00
#define COLOR_OLIVE   0x808000
#define COLOR_LIME    0x00FF00
#define COLOR_GREEN   0x008000
#define COLOR_AQUA    0x00FFFF
#define COLOR_TEAL    0x008080
#define COLOR_BLUE    0x0000FF
#define COLOR_NAVY    0x000080
#define COLOR_FUCHSIA 0xFF00FF
#define COLOR_PURPLE  0x800080


// Date and time functions using a DS3231 RTC connected via I2C and Wire lib
RTC_DS3231 rtc;

#define STANDBY_MODE                0
#define WAIT_FOR_SECOND_PLAYER_MODE 1
#define LAUNCH_MODE                 2
#define PROGRESS_MODE               3
#define STOP_MODE                   4
int mode = STANDBY_MODE;

#define RED_PLAYER   0
#define GREEN_PLAYER 1
int firstPlayer = RED_PLAYER;

#define RED_STRIP 0
#define GREEN_STRIP 1
#define TOWARD_RED 0
#define TOWARD_GREEN 1
int ballStrip;
int ballDir;
int ballPos;
int ballInProgress;

unsigned long top;
int blinkState = 0;

uint8_t currentScoreRedPlayer = 0;
uint8_t currentScoreGreenPlayer = 0;

void setup() {
  // initialize serial communications at 115200 bps:
  Serial.begin(115200);

  // initialize hardware
  redButton.begin(RED_BUTTON_PIN, HIGH);
  greenButton.begin(GREEN_BUTTON_PIN, HIGH);

  redLed.begin(RED_LED_PIN);
  greenLed.begin(GREEN_LED_PIN);

  redStrip.begin();
  redStrip.show(); // Initialize all pixels to 'off'

  greenStrip.begin();
  greenStrip.show(); // Initialize all pixels to 'off'

  if (! rtc.begin()) {
    Serial.println("Couldn't find RTC");
    while (1);
  }

  delay(3000);
  sendDate();
  Serial.println("/BOOT");
  delay(500);
  Serial.println("/DISPLAY_DATE");
  delay(2000);
  theaterChaseRainbow(50);
  Serial.println("/STANDBY");
  mode = STANDBY_MODE;
}

void loop() {
  // MODE : standby
  top = millis();
  while (mode == STANDBY_MODE) {
    if (millis() > (top + BLINK_DELAY)) {
      if (blinkState) {
        // strips and buttons on
        for (int i = (RED_STRIP_LENGTH - racketLength); i < RED_STRIP_LENGTH; i++) {
          redStrip.setPixelColor(i, COLOR_MAROON);
        }
        for (int i = (GREEN_STRIP_LENGTH - racketLength); i < GREEN_STRIP_LENGTH; i++) {
          greenStrip.setPixelColor(i, COLOR_GREEN);
        }
        redStrip.show();
        greenStrip.show();
        redLed.on();
        greenLed.on();
      }
      else {
        // strips and buttons off
        redStrip.clear();
        greenStrip.clear();
        redStrip.show();
        greenStrip.show();
        redLed.off();
        greenLed.off();
      }
      top = millis();
      blinkState = 1 - blinkState;
    }

    // is a button pressed ?
    redButton.read();
    greenButton.read();
    if (redButton.isJustOn()) {
      mode = WAIT_FOR_SECOND_PLAYER_MODE;
      firstPlayer = RED_PLAYER;
      Serial.println("/WAIT_GREEN");
    }
    if (greenButton.isJustOn()) {
      mode = WAIT_FOR_SECOND_PLAYER_MODE;
      firstPlayer = GREEN_PLAYER;
      Serial.println("/WAIT_RED");
    }

    // wait a little ...
    delay(20);
  }

  if (mode == WAIT_FOR_SECOND_PLAYER_MODE) {

    // MODE : wait for a second player
    // first player button and strip on
    // second player button and strip blink

    if (firstPlayer == RED_PLAYER) {
      for (int i = (RED_STRIP_LENGTH - racketLength); i < RED_STRIP_LENGTH; i++) {
        redStrip.setPixelColor(i, COLOR_MAROON);
      }
      redStrip.show();
      redLed.on();
    }
    else {
      for (int i = (GREEN_STRIP_LENGTH - racketLength); i < GREEN_STRIP_LENGTH; i++) {
        greenStrip.setPixelColor(i, COLOR_GREEN);
      }
      greenStrip.show();
      greenLed.on();
    }

    top = millis();
    stopTop = millis();
    blinkState = 1;
    while (mode == WAIT_FOR_SECOND_PLAYER_MODE) {
      if (millis() > (top + BLINK_DELAY)) {
        if (blinkState) {
          if (firstPlayer == RED_PLAYER) {
            for (int i = (GREEN_STRIP_LENGTH - racketLength); i < GREEN_STRIP_LENGTH; i++) {
              greenStrip.setPixelColor(i, COLOR_GREEN);
            }
            greenStrip.show();
            greenLed.on();
          }
          else {
            for (int i = (RED_STRIP_LENGTH - racketLength); i < RED_STRIP_LENGTH; i++) {
              redStrip.setPixelColor(i, COLOR_MAROON);
            }
            redStrip.show();
            redLed.on();
          }
        }
        else {
          if (firstPlayer == RED_PLAYER) {
            greenStrip.clear();
            greenStrip.show();
            greenLed.off();
          }
          else {
            redStrip.clear();
            redStrip.show();
            redLed.off();
          }
        }
        top = millis();
        blinkState = 1 - blinkState;
      }

      if (millis() > (stopTop + STOP_DELAY)) {
        Serial.println("/STANDBY");
        mode = STANDBY_MODE;
      }

      if (firstPlayer == RED_PLAYER) {
        greenButton.read();
        if (greenButton.isJustOn()) {
          mode = LAUNCH_MODE;
        }
      }
      else {
        redButton.read();
        if (redButton.isJustOn()) {
          mode = LAUNCH_MODE;
        }
      }

      // wait a little ...
      delay(20);
    }

  } // end WAIT_FOR_SECOND_PLAYER_MODE

  if (mode == LAUNCH_MODE) {

    // MODE : LAUNCH

    // every 2 games, racket length decreases
    // update racket length
    //int n = (currentScoreRedPlayer + currentScoreGreenPlayer) / 2;
    //racketLength = max(DEFAULT_RACKET_LENGTH - n, MIN_RACKET_LENGTH);

    // every 2 games, racket length decreases
    // update racket length
    int n = currentScoreRedPlayer + currentScoreGreenPlayer;
    racketLength = max(DEFAULT_RACKET_LENGTH - n, MIN_RACKET_LENGTH);

    // update speed
    //ballSpeed = max(DEFAULT_BALL_SPEED - (2 * n), MAX_BALL_SPEED);
    //ballSpeed = DEFAULT_BALL_SPEED;

    if (n == 0) {
      ballSpeed = DEFAULT_BALL_SPEED;
    }
    else {
      ballSpeed = DEFAULT_BALL_SPEED - 5;
    }


    if (firstPlayer == RED_PLAYER) {
      Serial.println("/LAUNCH_RED");
    }
    else {
      Serial.println("/LAUNCH_GREEN");
    }

    // on affiche les raquettes
    // la balle (bleue) clignote au bout du ruban du joueur 1

    // on affiche les raquettes et les boutons
    redStrip.clear();
    greenStrip.clear();
    for (int i = (RED_STRIP_LENGTH - racketLength); i < RED_STRIP_LENGTH; i++) {
      redStrip.setPixelColor(i, COLOR_MAROON);
    }
    for (int i = (GREEN_STRIP_LENGTH - racketLength); i < GREEN_STRIP_LENGTH; i++) {
      greenStrip.setPixelColor(i, COLOR_GREEN);
    }
    redStrip.show();
    greenStrip.show();
    redLed.on();
    greenLed.on();

    // on fait clignoter la led du coté du joueur qui a la main
    blinkState = 1;
    top = millis();
    stopTop = millis();
    while (mode == LAUNCH_MODE) {
      if (millis() > (top + BLINK_DELAY)) {
        if (blinkState) {
          if (firstPlayer == RED_PLAYER) {
            redStrip.setPixelColor(RED_STRIP_LENGTH - 1, COLOR_BLUE);
            redStrip.show();
          }
          else {
            greenStrip.setPixelColor(GREEN_STRIP_LENGTH - 1, COLOR_BLUE);
            greenStrip.show();
          }
        }
        else {
          if (firstPlayer == RED_PLAYER) {
            redStrip.setPixelColor(RED_STRIP_LENGTH - 1, COLOR_MAROON);
            redStrip.show();
          }
          else {
            greenStrip.setPixelColor(GREEN_STRIP_LENGTH - 1, COLOR_GREEN);
            greenStrip.show();
          }
        }
        top = millis();
        blinkState = 1 - blinkState;
      }

      if (millis() > (stopTop + STOP_DELAY)) {
        mode = STOP_MODE;
      }

      if (firstPlayer == RED_PLAYER) {
        redButton.read();
        if (redButton.isJustOn()) {
          mode = PROGRESS_MODE;
        }
      }
      else {
        greenButton.read();
        if (greenButton.isJustOn()) {
          mode = PROGRESS_MODE;
        }
      }

      // wait a little ...
      delay(20);
    }

  } // end LAUNCH_MODE

  if (mode == PROGRESS_MODE) {
    // PROGRESS MODE
    //   la balle avance tant que :
    //       - elle n'a pas atteint l'extremité du ruban
    //       - le joueur 2 n'a pas appuyé sur son bouton

    Serial.println("/PROGRESS");


    if (firstPlayer == RED_PLAYER) {
      // red player starts
      ballStrip = RED_STRIP;
      ballDir = TOWARD_GREEN;
      ballPos = (RED_STRIP_LENGTH - 1);
    }
    else {
      // green player starts
      ballStrip = GREEN_STRIP;
      ballDir = TOWARD_RED;
      ballPos = (GREEN_STRIP_LENGTH - 1);
    }

    // display racket for both players
    redStrip.clear();
    greenStrip.clear();

    for (int i = (RED_STRIP_LENGTH - racketLength); i < RED_STRIP_LENGTH; i++) {
      redStrip.setPixelColor(i, COLOR_MAROON);
    }

    for (int i = (GREEN_STRIP_LENGTH - racketLength); i < GREEN_STRIP_LENGTH; i++) {
      greenStrip.setPixelColor(i, COLOR_GREEN);
    }

    redStrip.show();
    greenStrip.show();

    ballInProgress = 1;

    while (ballInProgress) {
      if (ballStrip == RED_STRIP) {
        // the ball is on the red strip
        if (ballDir == TOWARD_GREEN) {
          // the ball is in the direction of the green button
          if (ballPos >= 0) {
            // clear red strip
            redStrip.clear();
            // display red racket
            for (int i = (RED_STRIP_LENGTH - racketLength); i < RED_STRIP_LENGTH; i++) {
              redStrip.setPixelColor(i, COLOR_MAROON);
            }
            // display the ball
            redStrip.setPixelColor(ballPos, COLOR_BLUE);
            redStrip.show();
            // move the ball
            ballPos -= 1;
          }
          else {
            // the ball go over the green strip
            //delay(ballSpeed * 10); // transition a travers l'écran
            ballStrip = GREEN_STRIP;
            ballPos = 0;
            // clear red strip
            redStrip.clear();
            // display red racket
            for (int i = (RED_STRIP_LENGTH - racketLength); i < RED_STRIP_LENGTH; i++) {
              redStrip.setPixelColor(i, COLOR_MAROON);
            }
            redStrip.show();
          }
        }
        else {
          // the ball is in the direction of the red button
          if (ballPos < RED_STRIP_LENGTH) {
            // clear red strip
            redStrip.clear();
            // display red racket
            for (int i = (RED_STRIP_LENGTH - racketLength); i < RED_STRIP_LENGTH; i++) {
              redStrip.setPixelColor(i, COLOR_MAROON);
            }
            // display the ball
            redStrip.setPixelColor(ballPos, COLOR_BLUE);
            redStrip.show();
            // move the ball
            ballPos += 1;
          }
          else {
            // the ball reached the end of the red strip
            // the red player lose
            ballInProgress = 0;
            currentScoreGreenPlayer++;
            Serial.print("/SCORE_GREEN ");
            Serial.println(currentScoreGreenPlayer, DEC);
            Serial.println("/WINNER_GREEN");
            theaterChaseGreen(50);
            //delay(5000);
            firstPlayer = RED_PLAYER;
            mode = LAUNCH_MODE;
          }
        }
      }
      else {
        // the ball is on the green strip
        if (ballDir == TOWARD_GREEN) {
          // the ball is in the direction of the green button
          if (ballPos < GREEN_STRIP_LENGTH) {
            // clear green strip
            greenStrip.clear();
            // display green racket
            for (int i = (GREEN_STRIP_LENGTH - racketLength); i < GREEN_STRIP_LENGTH; i++) {
              greenStrip.setPixelColor(i, COLOR_GREEN);
            }
            // display the ball
            greenStrip.setPixelColor(ballPos, COLOR_BLUE);
            greenStrip.show();
            // move the ball
            ballPos += 1;
          }
          else {
            // the ball reached the end of the green strip
            // the green player lose
            ballInProgress = 0;
            currentScoreRedPlayer++;
            Serial.print("/SCORE_RED ");
            Serial.println(currentScoreRedPlayer, DEC);
            Serial.println("/WINNER_RED");
            theaterChaseRed(50);
            //delay(5000);
            firstPlayer = GREEN_PLAYER;
            mode = LAUNCH_MODE;
          }
        }
        else {
          // the ball is in the direction of the red button
          if (ballPos >= 0) {
            // clear green strip
            greenStrip.clear();
            // display green racket
            for (int i = (GREEN_STRIP_LENGTH - racketLength); i < GREEN_STRIP_LENGTH; i++) {
              greenStrip.setPixelColor(i, COLOR_GREEN);
            }
            // display the ball
            greenStrip.setPixelColor(ballPos, COLOR_BLUE);
            greenStrip.show();
            // move the ball
            ballPos -= 1;
          }
          else {
            // the ball go over the red strip
            //delay(ballSpeed * 10); // transition a travers l'écran
            ballStrip = RED_STRIP;
            ballPos = 0;
            // clear green strip
            greenStrip.clear();
            // display green racket
            for (int i = (GREEN_STRIP_LENGTH - racketLength); i < GREEN_STRIP_LENGTH; i++) {
              greenStrip.setPixelColor(i, COLOR_GREEN);
            }
            greenStrip.show();
          }
        }
      }


      // is a button pressed ?
      redButton.read();
      greenButton.read();
      if (redButton.isJustOn() and ballDir == TOWARD_RED) {
        if (ballStrip == RED_STRIP and (ballPos >= (RED_STRIP_LENGTH - racketLength))) {
          // the red player send back the ball
          ballSpeed = max(ballSpeed - 2, MAX_BALL_SPEED); // speed up!
          ballDir = TOWARD_GREEN;
        }
        else {
          // the red player lose!
          ballInProgress = 0;
          currentScoreGreenPlayer++;
          Serial.print("/SCORE_GREEN ");
          Serial.println(currentScoreGreenPlayer, DEC);
          Serial.println("/WINNER_GREEN");
          theaterChaseGreen(50);
          //delay(5000);
          firstPlayer = RED_PLAYER;
          mode = LAUNCH_MODE;
        }
      }
      if (greenButton.isJustOn() and ballDir == TOWARD_GREEN) {
        if (ballStrip == GREEN_STRIP and (ballPos >= (GREEN_STRIP_LENGTH - racketLength))) {
          // the green player send back the ball
          ballSpeed = max(ballSpeed - 2, MAX_BALL_SPEED); // speed up!
          ballDir = TOWARD_RED;
        }
        else {
          // the green player lose!
          ballInProgress = 0;
          currentScoreRedPlayer++;
          Serial.print("/SCORE_RED ");
          Serial.println(currentScoreRedPlayer, DEC);
          Serial.println("/WINNER_RED");
          theaterChaseRed(50);
          //delay(5000);
          firstPlayer = GREEN_PLAYER;
          mode = LAUNCH_MODE;
        }
      }
      delay(ballSpeed);
    }
  } // end PROGRESS_MODE

  if (mode == STOP_MODE) {
    sendDate();
    Serial.println("/SAVE");
    delay(500);
    // qui a gagné ?
    if (currentScoreRedPlayer > currentScoreGreenPlayer) {
      Serial.println("/STOP_RED");
      theaterChaseRed(50);
    }
    else if (currentScoreRedPlayer < currentScoreGreenPlayer) {
      Serial.println("/STOP_GREEN");
      theaterChaseGreen(50);
    }
    else {
      Serial.println("/STOP_DRAW");
      theaterChaseRainbow(50);
    }
    //delay(5000);

    // nouvelle partie
    mode = STANDBY_MODE;
    Serial.println("/STANDBY");
    currentScoreRedPlayer = 0;
    currentScoreGreenPlayer = 0;
    Serial.println("/SCORE_RED 0");
    Serial.println("/SCORE_GREEN 0");
    racketLength = DEFAULT_RACKET_LENGTH;
    ballSpeed = DEFAULT_BALL_SPEED;
  } // end STOP_MODE

}

//Theatre-style crawling lights.
void theaterChaseRed(uint8_t wait) {
  for (int j = 0; j < 25; j++) { //do 25 cycles of chasing
    for (int q = 0; q < 3; q++) {
      for (uint16_t i = 0; i < RED_STRIP_LENGTH; i = i + 3) {
        redStrip.setPixelColor(i + q, COLOR_MAROON);  //turn every third pixel on
      }
      redStrip.show();

      delay(wait);

      for (uint16_t i = 0; i < RED_STRIP_LENGTH; i = i + 3) {
        redStrip.setPixelColor(i + q, 0);      //turn every third pixel off
      }
    }
  }
}

void theaterChaseGreen(uint8_t wait) {
  for (int j = 0; j < 25; j++) { //do 25 cycles of chasing
    for (int q = 0; q < 3; q++) {
      for (uint16_t i = 0; i < GREEN_STRIP_LENGTH; i = i + 3) {
        greenStrip.setPixelColor(i + q, COLOR_GREEN);  //turn every third pixel on
      }
      greenStrip.show();

      delay(wait);

      for (uint16_t i = 0; i < GREEN_STRIP_LENGTH; i = i + 3) {
        greenStrip.setPixelColor(i + q, 0);      //turn every third pixel off
      }
    }
  }
}

//Theatre-style crawling lights with rainbow effect
void theaterChaseRainbow(uint8_t wait) {
  for (int j = 0; j < 256; j = j + 8) { // cycle all 256 colors in the wheel
    for (int q = 0; q < 3; q++) {
      for (uint16_t i = 0; i < RED_STRIP_LENGTH; i = i + 3) {
        redStrip.setPixelColor(i + q, Wheel( (i + j) % 255)); //turn every third pixel on
      }
      for (uint16_t i = 0; i < GREEN_STRIP_LENGTH; i = i + 3) {
        greenStrip.setPixelColor(i + q, Wheel( (i + j) % 255)); //turn every third pixel on
      }
      redStrip.show();
      greenStrip.show();

      delay(wait);

      for (uint16_t i = 0; i < RED_STRIP_LENGTH; i = i + 3) {
        redStrip.setPixelColor(i + q, 0);      //turn every third pixel off
      }
      for (uint16_t i = 0; i < GREEN_STRIP_LENGTH; i = i + 3) {
        greenStrip.setPixelColor(i + q, 0);      //turn every third pixel off
      }
    }
  }
}

// Input a value 0 to 255 to get a color value.
// The colours are a transition r - g - b - back to r.
uint32_t Wheel(byte WheelPos) {
  WheelPos = 255 - WheelPos;
  if (WheelPos < 85) {
    return redStrip.Color(255 - WheelPos * 3, 0, WheelPos * 3);
  }
  if (WheelPos < 170) {
    WheelPos -= 85;
    return redStrip.Color(0, WheelPos * 3, 255 - WheelPos * 3);
  }
  WheelPos -= 170;
  return redStrip.Color(WheelPos * 3, 255 - WheelPos * 3, 0);
}

void sendDate() {
  DateTime now = rtc.now();
  //Serial.println(now.unixtime());
  Serial.print("/YEAR ");
  Serial.println(now.year() - 2000, DEC);
  Serial.print("/MONTH ");
  Serial.println(now.month(), DEC);
  Serial.print("/DAY ");
  Serial.println(now.day(), DEC);
  Serial.print("/HOUR ");
  Serial.println(now.hour(), DEC);
  Serial.print("/MINUTE ");
  Serial.println(now.minute(), DEC);
}

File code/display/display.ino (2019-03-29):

// include the SD library:
#include <SD.h>
#include <SPI.h>

// change this to match your SD shield or module;
// Teensy 3.5 & 3.6 on-board: BUILTIN_SDCARD
const int chipSelect = BUILTIN_SDCARD;

bool SdCardAvailable = true;


#include <EEPROM.h>
uint8_t lastScoreRedPlayer = 12;
uint8_t lastScoreGreenPlayer = 15;
uint8_t lastScoreYear = 0;
uint8_t lastScoreMonth = 0;
uint8_t lastScoreDay = 0;
uint8_t lastScoreHour = 0;
uint8_t lastScoreMinute = 0;

uint8_t bestScoreRedPlayer = 30;
uint8_t bestScoreGreenPlayer = 19;
uint8_t bestScoreYear = 0;
uint8_t bestScoreMonth = 0;
uint8_t bestScoreDay = 0;
uint8_t bestScoreHour = 0;
uint8_t bestScoreMinute = 0;

uint8_t currentScoreRedPlayer = 0;
uint8_t currentScoreGreenPlayer = 0;
uint8_t currentYear = 0;
uint8_t currentMonth = 1;
uint8_t currentDay = 1;
uint8_t currentHour = 0;
uint8_t currentMinute = 0;

unsigned long top;
int blinkOn = 0;
#define BLINK_DELAY     500
#define SCREEN_DELAY   5000
#define WAIT_DELAY    10000
int standbyChange = 0;

// progress bar
unsigned long progressTop;
int progressBar = 0;
#define PROGRESS_LENGHT  63
// 10000 / 64 = 156
#define PROGRESS_DELAY  156

#include <SmartLEDShieldV4.h>  // comment out this line for if you're not using SmartLED Shield V4 hardware (this line needs to be before #include <SmartMatrix3.h>)
#include <SmartMatrix3.h>

// uncomment if you want to debug
//#define DEBUG

#define COLOR_DEPTH 24                  // known working: 24, 48 - If the sketch uses type `rgb24` directly, COLOR_DEPTH must be 24
const uint8_t kMatrixWidth = 64;        // known working: 32, 64, 96, 128
const uint8_t kMatrixHeight = 32;       // known working: 16, 32, 48, 64
const uint8_t kRefreshDepth = 36;       // known working: 24, 36, 48
const uint8_t kDmaBufferRows = 4;       // known working: 2-4, use 2 to save memory, more to keep from dropping frames and automatically lowering refresh rate
const uint8_t kPanelType = SMARTMATRIX_HUB75_32ROW_MOD16SCAN; // use SMARTMATRIX_HUB75_16ROW_MOD8SCAN for common 16x32 panels, or use SMARTMATRIX_HUB75_64ROW_MOD32SCAN for common 64x64 panels
const uint8_t kMatrixOptions = (SMARTMATRIX_OPTIONS_NONE);      // see http://docs.pixelmatix.com/SmartMatrix for options
const uint8_t kBackgroundLayerOptions = (SM_BACKGROUND_OPTIONS_NONE);

SMARTMATRIX_ALLOCATE_BUFFERS(matrix, kMatrixWidth, kMatrixHeight, kRefreshDepth, kDmaBufferRows, kPanelType, kMatrixOptions);
SMARTMATRIX_ALLOCATE_BACKGROUND_LAYER(backgroundLayer, kMatrixWidth, kMatrixHeight, COLOR_DEPTH, kBackgroundLayerOptions);

#define FULL_BRIGHTNESS 255
//const rgb24 defaultBackgroundColor = {0, 0, 0};

// HTML colors
#define COLOR_WHITE   {0xff, 0xff, 0xff}
#define COLOR_SILVER  {0xc0, 0xc0, 0xc0}
#define COLOR_GRAY    {0x80, 0x80, 0x80}
#define COLOR_BLACK   {0, 0, 0}
#define COLOR_RED     {0xff, 0, 0}
#define COLOR_MAROON  {0x80, 0, 0}
#define COLOR_YELLOW  {0xff, 0xff, 0}
#define COLOR_OLIVE   {0x80, 0x80, 0}
#define COLOR_LIME    {0, 0xff, 0}
#define COLOR_GREEN   {0, 0x80, 0}
#define COLOR_AQUA    {0, 0xff, 0xff}
#define COLOR_TEAL    {0, 0x80, 0x80}
#define COLOR_BLUE    {0, 0, 0xff}
#define COLOR_NAVY    {0, 0, 0x80}
#define COLOR_FUCHSIA {0xff, 0, 0xff}
#define COLOR_PURPLE  {0x80, 0, 0x80}


// variables for serial reading
char receivedChar = '0';
String receivedString = "";
String message = "";

// commands
#define STANDBY       1
#define WAIT_RED      2
#define WAIT_GREEN    3
#define LAUNCH_RED    4
#define LAUNCH_GREEN  5
#define PROGRESS      6
#define WINNER_RED    7
#define WINNER_GREEN  8
#define STOP_RED      9
#define STOP_GREEN   10
#define SCORE_RED    11
#define SCORE_GREEN  12
#define BOOTING      13
#define YEAR         14
#define MONTH        15
#define DAY          16
#define HOUR         17
#define MINUTE       18
#define DISPLAY_DATE 19
#define STOP_DRAW    20
#define SAVE         21
#define BOOT         22
bool command_flag = false;
int command = 0;
bool value_flag = false;
int mode = 0;


void setup() {
  // init Serial communication
#ifdef DEBUG
  Serial.begin(115200);
#else
  Serial2.begin(115200);
#endif
  delay(200);

  if (!SD.begin(chipSelect)) {
    SdCardAvailable = false;
  }

  matrix.addLayer(&backgroundLayer);
  matrix.begin();
  matrix.setBrightness(FULL_BRIGHTNESS);
  backgroundLayer.enableColorCorrection(true);

  // reads values from EEPROM
  loadScores();

  // wait for Arduino Mega to start ...
  mode = BOOTING;

}


void loop() {
  // Listening to serial
#ifdef DEBUG
  while (Serial.available() > 0) {
    receivedChar = Serial.read();
#else
  while (Serial2.available() > 0) {
    receivedChar = Serial2.read();
#endif
    if (receivedChar == '/') {
      // Recieving command
      command_flag = true;
    }
    else if (receivedChar == '\n' || receivedChar == ' ' || receivedChar == 13) {
      // Message processing

      if (command_flag) {
        // Command processing

        if (receivedString == "SCORE_RED") {
          command = SCORE_RED;
          value_flag = true; // Waiting for a following argument
        }

        if (receivedString == "SCORE_GREEN") {
          command = SCORE_GREEN;
          value_flag = true; // Waiting for a following argument
        }

        if (receivedString == "YEAR") {
          command = YEAR;
          value_flag = true; // Waiting for a following argument
        }

        if (receivedString == "MONTH") {
          command = MONTH;
          value_flag = true; // Waiting for a following argument
        }

        if (receivedString == "DAY") {
          command = DAY;
          value_flag = true; // Waiting for a following argument
        }

        if (receivedString == "HOUR") {
          command = HOUR;
          value_flag = true; // Waiting for a following argument
        }

        if (receivedString == "MINUTE") {
          command = MINUTE;
          value_flag = true; // Waiting for a following argument
        }

        if (receivedString == "BOOT") {
          logBoot();
        }

        if (receivedString == "DISPLAY_DATE") {
          // display date
          mode = DISPLAY_DATE;
          top = 0; // refresh screen !
          progressBar = 0; // hide progress bar
        }

        if (receivedString == "STANDBY") {
          // standby mode
          mode = STANDBY;
          top = 0; // refresh screen !
          progressBar = 0; // hide progress bar
          standbyChange = 0;
        }

        if (receivedString == "WAIT_RED") {
          // wait for red player
          mode = WAIT_RED;
          top = 0; // refresh screen !
          progressBar = PROGRESS_LENGHT; // show progress bar
          progressTop = millis();
        }

        if (receivedString == "WAIT_GREEN") {
          // wait for green player
          mode = WAIT_GREEN;
          top = 0; // refresh screen !
          progressBar = PROGRESS_LENGHT; // show progress bar
          progressTop = millis();
        }
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
